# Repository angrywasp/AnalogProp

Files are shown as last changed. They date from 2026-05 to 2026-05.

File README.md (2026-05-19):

# AnalogProp
A Simple P8X32A propeller development board with AD7812 ADC

## Requirements

You will also need a couple of tool, which can be imnstalled from Nuget.  
- proptool, a basic command line tool for flashing the firmware and serial monitoring. Compatible with the AnalogProp or any propeller compatible USB-UART device such as the PropPlug  
- bsi, the BasicScript interpreter. BasicScript is a simple, cross platform interpreter scripting language that is used

dotnet tool install -g AngryWasp.PropTool AngryWasp.BasicScript.Interpreter  
dotnet tool install -g AngryWasp.BasicScript.Interpreter

You can find out more about these tools and download the source from their respective repos:  
BasicScript: https://github.com/AngryWasp/AngryWasp.BasicScript    
PropTool: https://github.com/AngryWasp/AngryWasp.PropTool  

## Compiling the example

Simplest is to just run 'helloWorld.bs'. This script calls make.bs to build and then install the helloWorld program   

```powershell
bsi ./helloWorld.bs
```

For complete control over the install, you can use proptool directly. run 'proptool --help' for a full list of available command line options

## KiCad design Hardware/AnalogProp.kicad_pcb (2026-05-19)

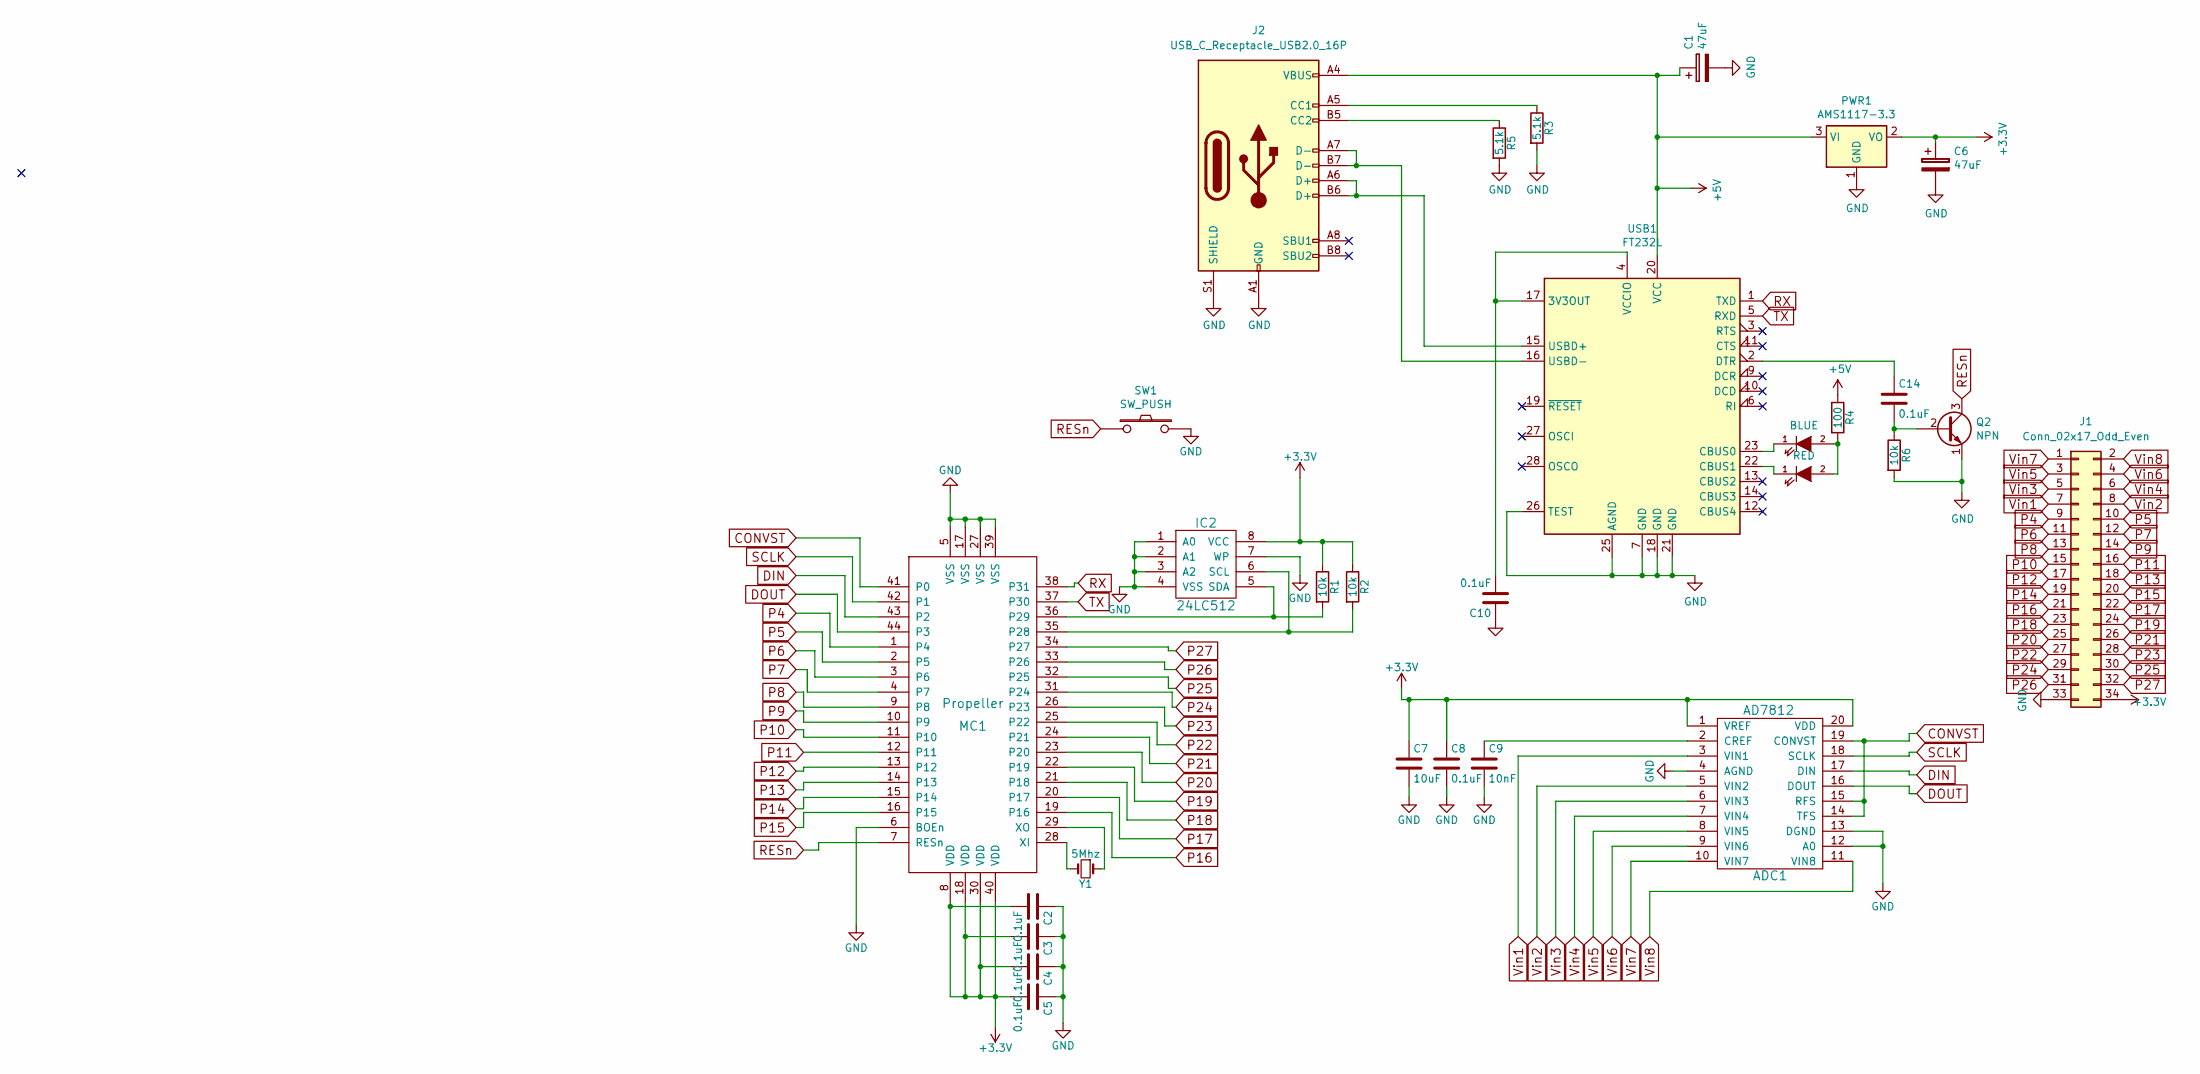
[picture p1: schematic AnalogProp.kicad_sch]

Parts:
ADC1: AD7812
C1, C6: 47uF; CP_Elec_5x5.4
C2, C3, C4, C5, C8, C10, C14: 0.1uF; 0805_HS
C7: 10uF; 0805_HS
C9: 10nF; 0805_HS
D2: BLUE; LED_0805_HS
D3: RED; LED_0805_HS
IC2: 24LC512; 24LC512-W
J1: Conn_02x17_Odd_Even; PinHeader_2x17_P2.54mm_Vertical
J2: USB_C_Receptacle_USB2.0_16P; USB_C_Receptacle_G-Switch_GT-USB-7010ASV
MC1: Propeller; P8X32A
PWR1: AMS1117-3.3; SOT-223
Q2: NPN; SOT-23_HS
R1, R2, R6: 10k; 0805_HS
R3, R5: 5.1k; 0805_HS
R4: 100; 0805_HS
SW1: SW_PUSH; SW_SPST
USB1: FT232L; SSOP-28_5.3x10.2mm_P0.65mm
Y1: 5Mhz; XTAL-2

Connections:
+3.3V: ADC1.1 (VREF), ADC1.20 (VDD), C2.2, C3.2, C4.2, C5.2, C6.1, C7.1, C8.1, IC2.8 (VCC), J1.34, MC1.8 (VDD), MC1.18 (VDD), MC1.30 (VDD), MC1.40 (VDD), PWR1.2 (VO), R1.1, R2.1
+5V: C1.1, J2.A4 (VBUS), J2.A9 (VBUS), J2.B4 (VBUS), J2.B9 (VBUS), PWR1.3 (VI), R4.1, USB1.20 (VCC)
CONVST: ADC1.14 (TFS), ADC1.15 (RFS), ADC1.19 (CONVST), MC1.41 (P0)
DIN: ADC1.17 (DIN), MC1.43 (P2)
DOUT: ADC1.16 (DOUT), MC1.44 (P3)
GND: ADC1.4 (AGND), ADC1.12 (A0), ADC1.13 (DGND), C1.2, C2.1, C3.1, C4.1, C5.1, C6.2, C7.2, C8.2, C9.2, C10.1, IC2.1 (A0), IC2.2 (A1), IC2.3 (A2), IC2.4 (VSS), IC2.7 (WP), J1.33, J2.A1 (GND), J2.A12 (GND), J2.B1 (GND), J2.B12 (GND), J2.S1 (SHIELD), MC1.5 (VSS), MC1.6 (BOEn), MC1.17 (VSS), MC1.27 (VSS), MC1.39 (VSS), PWR1.1 (GND), Q2.1 (E), R3.2, R5.2, R6.2, SW1.2, USB1.7 (GND), USB1.18 (GND), USB1.21 (GND), USB1.25 (AGND), USB1.26 (TEST)
unnamed: ADC1.2 (CREF), C9.1
unnamed: D2.2 (A), D3.2 (A), R4.2
unnamed: D2.1 (K), USB1.23 (CBUS0)
unnamed: D3.1 (K), USB1.22 (CBUS1)
unnamed: IC2.6 (SCL), MC1.35 (P28), R2.2
unnamed: IC2.5 (SDA), MC1.36 (P29), R1.2
unnamed: J2.A5 (CC1), R3.1
unnamed: J2.B5 (CC2), R5.1
unnamed: MC1.28 (XI), Y1.2
unnamed: MC1.29 (XO), Y1.1
unnamed: C14.2, Q2.2 (B), R6.1
unnamed: C10.2, USB1.4 (VCCIO), USB1.17 (3V3OUT)
unnamed: C14.1, USB1.2 (DTR)
unnamed: J2.A6 (D+), J2.B6 (D+), USB1.15 (USBD+)
unnamed: J2.A7 (D-), J2.B7 (D-), USB1.16 (USBD-)
P4: J1.9, MC1.1 (P4)
P5: J1.10, MC1.2 (P5)
P6: J1.11, MC1.3 (P6)
P7: J1.12, MC1.4 (P7)
P8: J1.13, MC1.9 (P8)
P9: J1.14, MC1.10 (P9)
P10: J1.15, MC1.11 (P10)
P11: J1.16, MC1.12 (P11)
P12: J1.17, MC1.13 (P12)
P13: J1.18, MC1.14 (P13)
P14: J1.19, MC1.15 (P14)
P15: J1.20, MC1.16 (P15)
P16: J1.21, MC1.19 (P16)
P17: J1.22, MC1.20 (P17)
P18: J1.23, MC1.21 (P18)
P19: J1.24, MC1.22 (P19)
P20: J1.25, MC1.23 (P20)
P21: J1.26, MC1.24 (P21)
P22: J1.27, MC1.25 (P22)
P23: J1.28, MC1.26 (P23)
P24: J1.29, MC1.31 (P24)
P25: J1.30, MC1.32 (P25)
P26: J1.31, MC1.33 (P26)
P27: J1.32, MC1.34 (P27)
RESn: MC1.7 (RESn), Q2.3 (C), SW1.1
RX: MC1.38 (P31), USB1.1 (TXD)
SCLK: ADC1.18 (SCLK), MC1.42 (P1)
TX: MC1.37 (P30), USB1.5 (RXD)
Vin1: ADC1.3 (VIN1), J1.7
Vin2: ADC1.5 (VIN2), J1.8
Vin3: ADC1.6 (VIN3), J1.5
Vin4: ADC1.7 (VIN4), J1.6
Vin5: ADC1.8 (VIN5), J1.3
Vin6: ADC1.9 (VIN6), J1.4
Vin7: ADC1.10 (VIN7), J1.1
Vin8: ADC1.11 (VIN8), J1.2

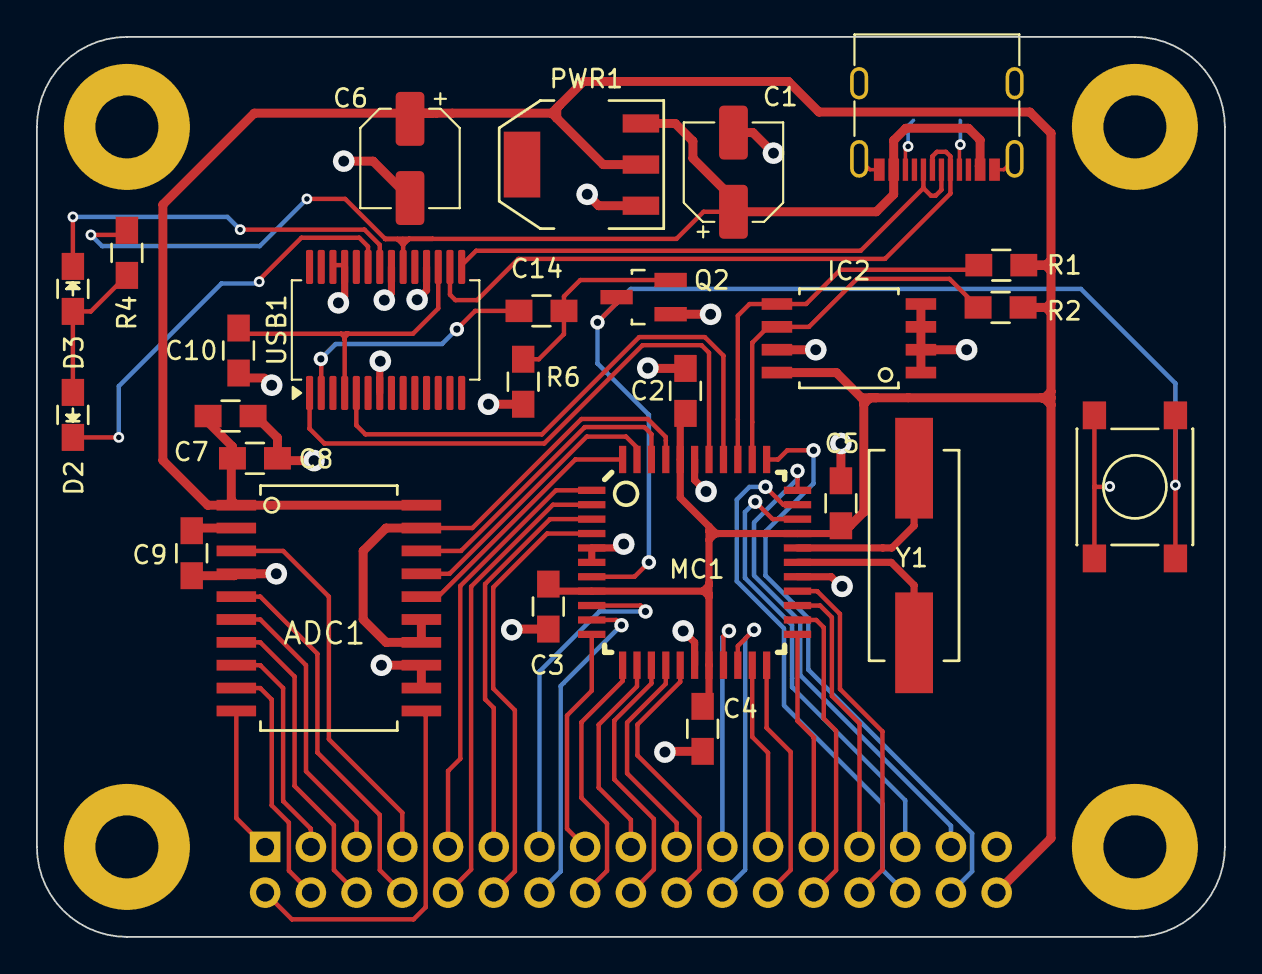
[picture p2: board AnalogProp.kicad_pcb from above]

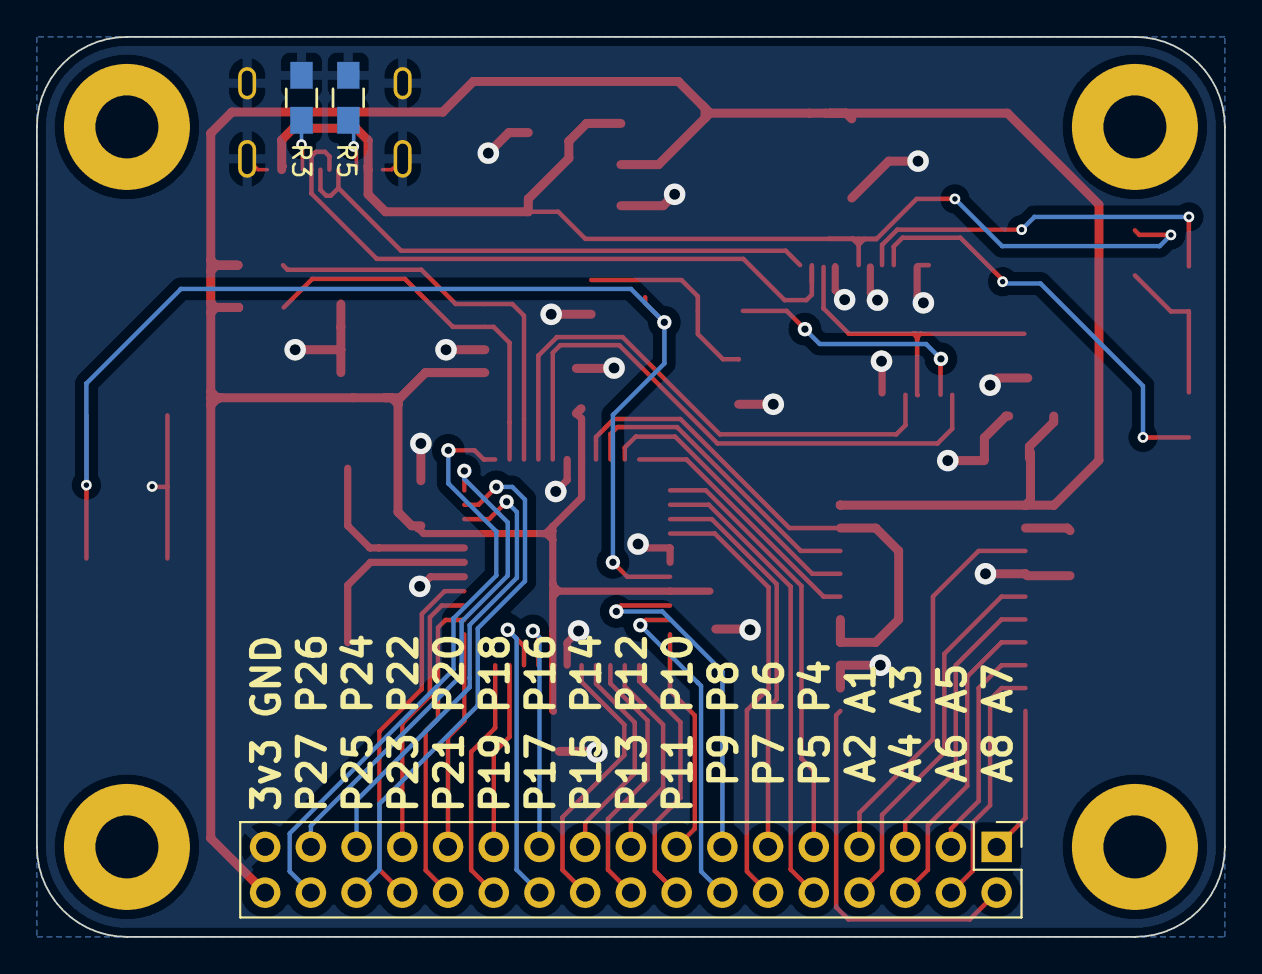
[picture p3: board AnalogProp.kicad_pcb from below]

Board: 2 copper layers, 66.0 x 50.0 mm, 29 parts (3 on the bottom side), 57 nets.
